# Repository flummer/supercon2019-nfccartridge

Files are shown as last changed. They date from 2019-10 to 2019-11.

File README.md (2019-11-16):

# NFC Cardtridge for the 2019 Hackaday Superconference Badge

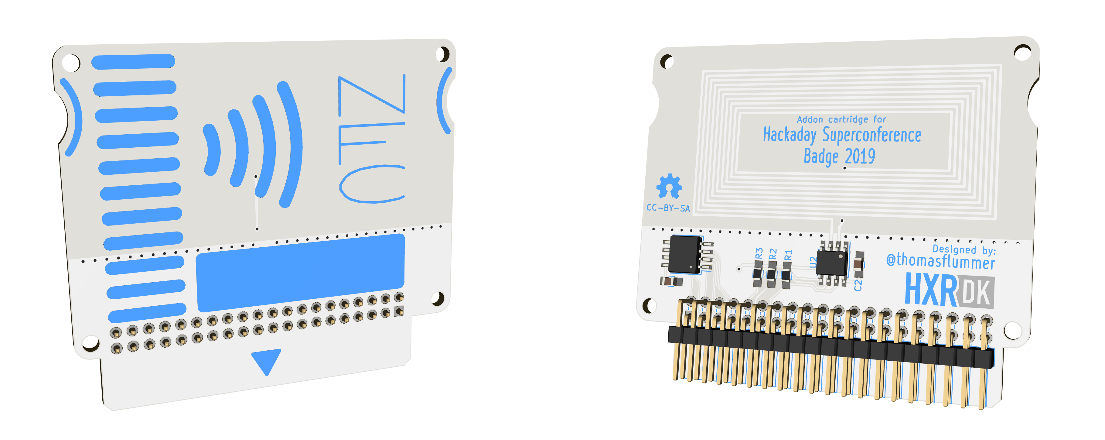
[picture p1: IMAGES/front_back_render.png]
NFC Cartridge render


This is a cartridge that provides an NFC tag using an ST25DV. In addition to the RF interface, that can be used without plugging in the cartridge, the ST25DV also have an I2C interface, that is connected to the IO pins on the badge connector, allowing the badge to access the same memory in the NFC tag chip.

This cartridge is based on the [unofficial Superconference 2019 Badge Cartridge template](https://github.com/flummer/supercon2019-cartridgetemplate) and hence include the w25q128 SPI flash and a 100nF cap in addition to the 2x20 pin angled male pin header for the badge connection. The flash allows badge configurations and firmware specific to this cartridge to be loaded from the cartridge it self making it selfcontained.

## Version 1.2 update

This updated version fixes an error in the pin connections on the cartridge connector (the two columns was flipped for some signals).

## Special note about the original version

If you want to use a PCB based on the original version with incorrect connections, it is possible to make a hardware hack on the 20x2 angeled header, where you move the pins around and bend some of them a bit, very precisely.

## License

The contents of this repository is released under the following licence:

 * the "Creative Commons Attribution-ShareAlike 4.0 International License"
   (CC BY-SA 4.0) full text of this license is included in the LICENSE file
   and a copy can also be found at
   http://creativecommons.org/licenses/by-sa/4.0/

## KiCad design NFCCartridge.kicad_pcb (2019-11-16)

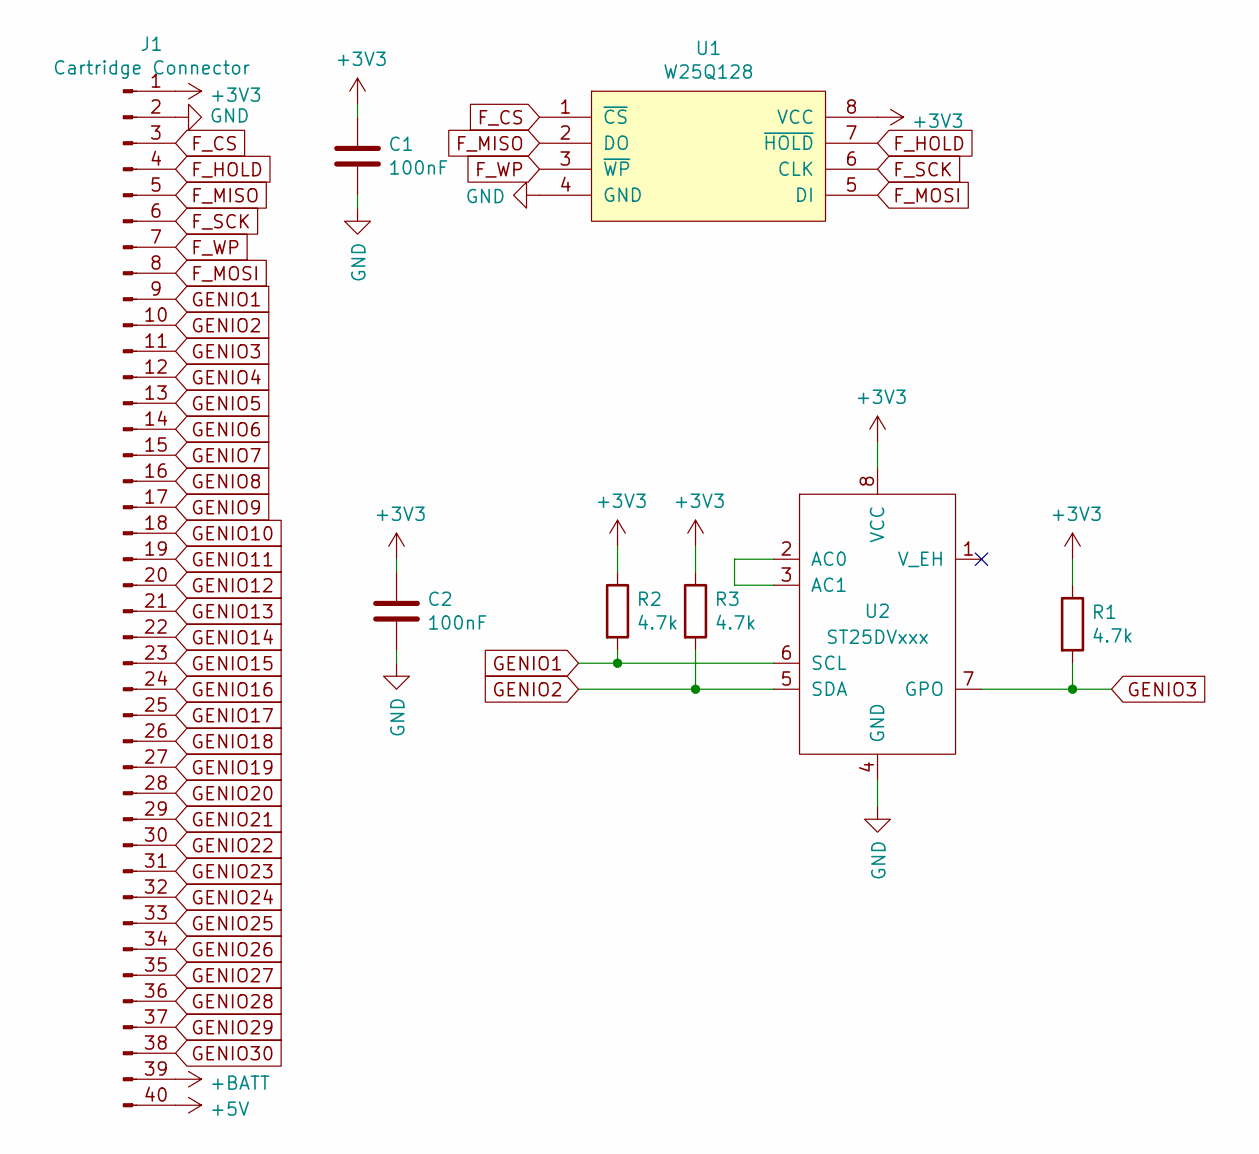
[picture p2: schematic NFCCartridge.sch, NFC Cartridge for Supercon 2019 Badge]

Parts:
C1, C2: 100nF; C_0805_HandSoldering
J1: Cartridge Connector; Supercon_Cartridge_40pin_Connector
R1, R2, R3: 4.7k; R_0805_HandSoldering
U1: W25Q128; SO-8_5.3x6.2mm_Pitch1.27mm
U2: ST25DVxxx; SOIC-8_3.9x4.9mm_Pitch1.27mm

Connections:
+3V3: C1.1, C2.1, J1.1, R1.1, R2.1, R3.1, U1.8 (VCC), U2.8 (VCC)
+5V: J1.40
+BATT: J1.39
F_CS: J1.3, U1.1 (~CS)
F_HOLD: J1.4, U1.7 (~HOLD)
F_MISO: J1.5, U1.2 (DO)
F_MOSI: J1.8, U1.5 (DI)
F_SCK: J1.6, U1.6 (CLK)
F_WP: J1.7, U1.3 (~WP)
GENIO1: J1.9, R2.2, U2.6 (SCL)
GENIO2: J1.10, R3.2, U2.5 (SDA)
GENIO3: J1.11, R1.2, U2.7 (GPO)
GENIO4: J1.12
GENIO5: J1.13
GENIO6: J1.14
GENIO7: J1.15
GENIO8: J1.16
GENIO9: J1.17
GENIO10: J1.18
GENIO11: J1.19
GENIO12: J1.20
GENIO13: J1.21
GENIO14: J1.22
GENIO15: J1.23
GENIO16: J1.24
GENIO17: J1.25
GENIO18: J1.26
GENIO19: J1.27
GENIO20: J1.28
GENIO21: J1.29
GENIO22: J1.30
GENIO23: J1.31
GENIO24: J1.32
GENIO25: J1.33
GENIO26: J1.34
GENIO27: J1.35
GENIO28: J1.36
GENIO29: J1.37
GENIO30: J1.38
GND: C1.2, C2.2, J1.2, U1.4 (GND), U2.4 (GND)
unnamed: U2.2 (AC0), U2.3 (AC1)

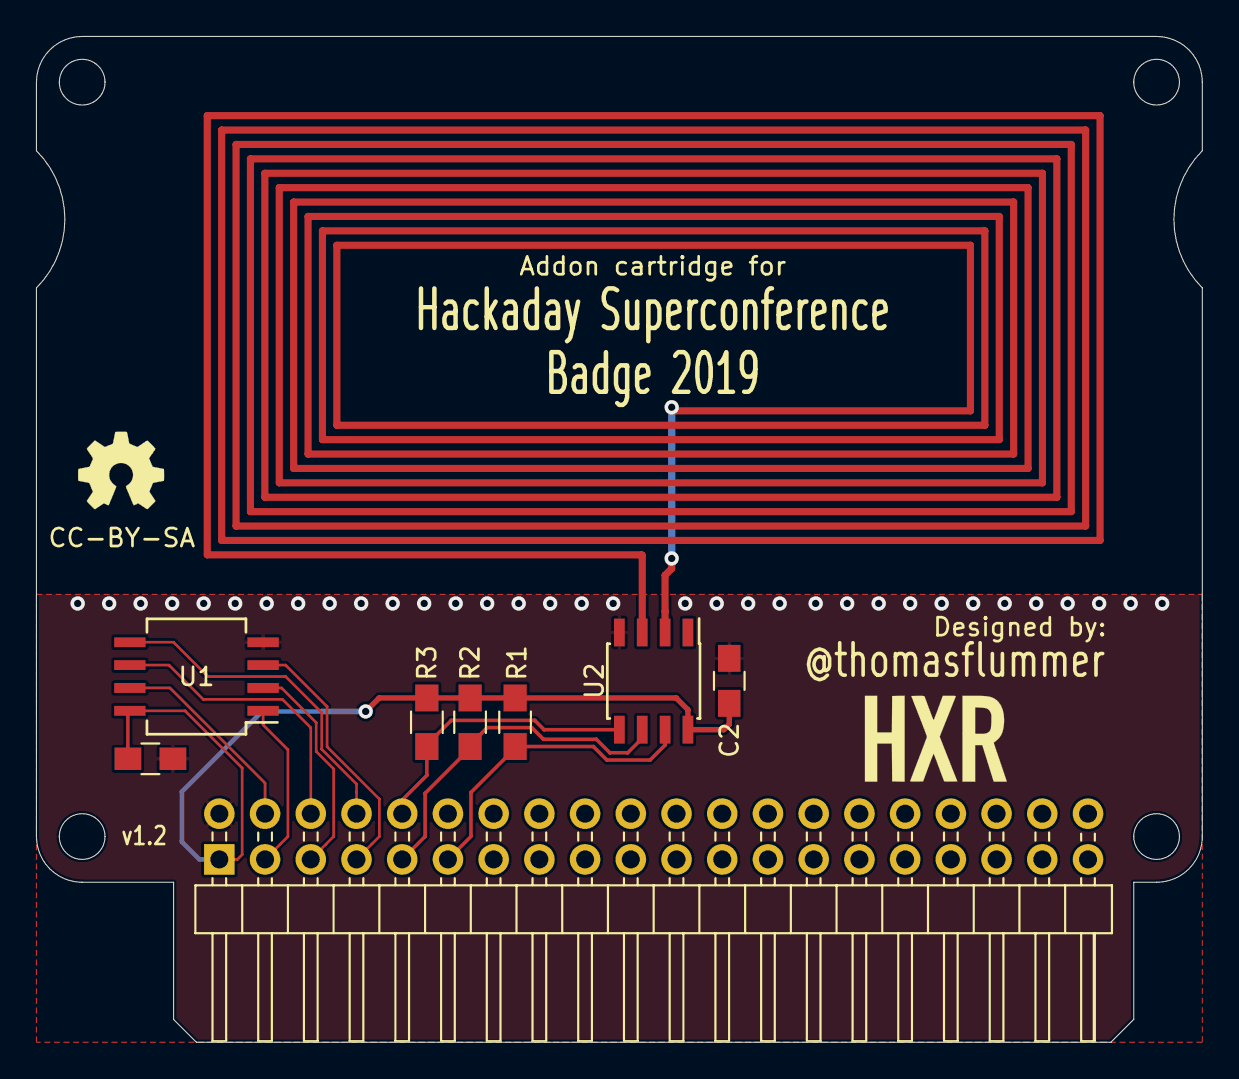
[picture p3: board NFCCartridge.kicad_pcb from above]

Board: 2 copper layers, 64.8 x 55.9 mm, 8 parts (0 on the bottom side), 12 nets.

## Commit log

2019-10-29 First design of the NFC Cartridge
    [CartridgeTemplate.kicad_pcb, NFCCartridge.kicad_pcb, NFCCartridge.sch]
2019-11-16 Fixed error in cartridge connector pin assignments
    Updated to version 1.2
    [NFCCartridge.kicad_pcb, NFCCartridge.sch]
